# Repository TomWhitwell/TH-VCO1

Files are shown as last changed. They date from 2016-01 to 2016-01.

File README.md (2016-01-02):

# TH-VCO1

This is a Eurorack Layout for the [Thomas Henry VCO 1](http://www.birthofasynth.com/Thomas_Henry/Pages/VCO-1.html) Oscillator. 

**NB: All rights to this design rest with Thomas Henry. I do not claim or grant any copyright or license to this design. I am not selling any boards. I have not been able to contact Thomas, and will take this page down if he asks me to.** 

I made very minor changes from Thomas' original to make it work on 12v - detailed here: https://muffwiggler.com/forum/viewtopic.php?t=49671

This layout is for a modern LM13700 OTA replacing the old 3080, with a That 340 chip providing the matched transistor pairs. The only other non-standard components are a [2K 3300ppm Tempco](https://www.thonk.co.uk/shop/tempco-resistor-anakeohm-1-3300ppm-x3/) as R2, and a Polystyrene 1nf cap as C3.  

It all works very well, fantastic FM, nice looking and sounding sines. I was able to trim it to 4-5 octaves before getting bored. I haven't used multi-turn trimmers, so it might be harder to trim more accurately. On my second build I haven't trimmed anything, and it works beautifully for my needs. 

Quick demo here: https://www.instagram.com/p/_etQT6DmdM/

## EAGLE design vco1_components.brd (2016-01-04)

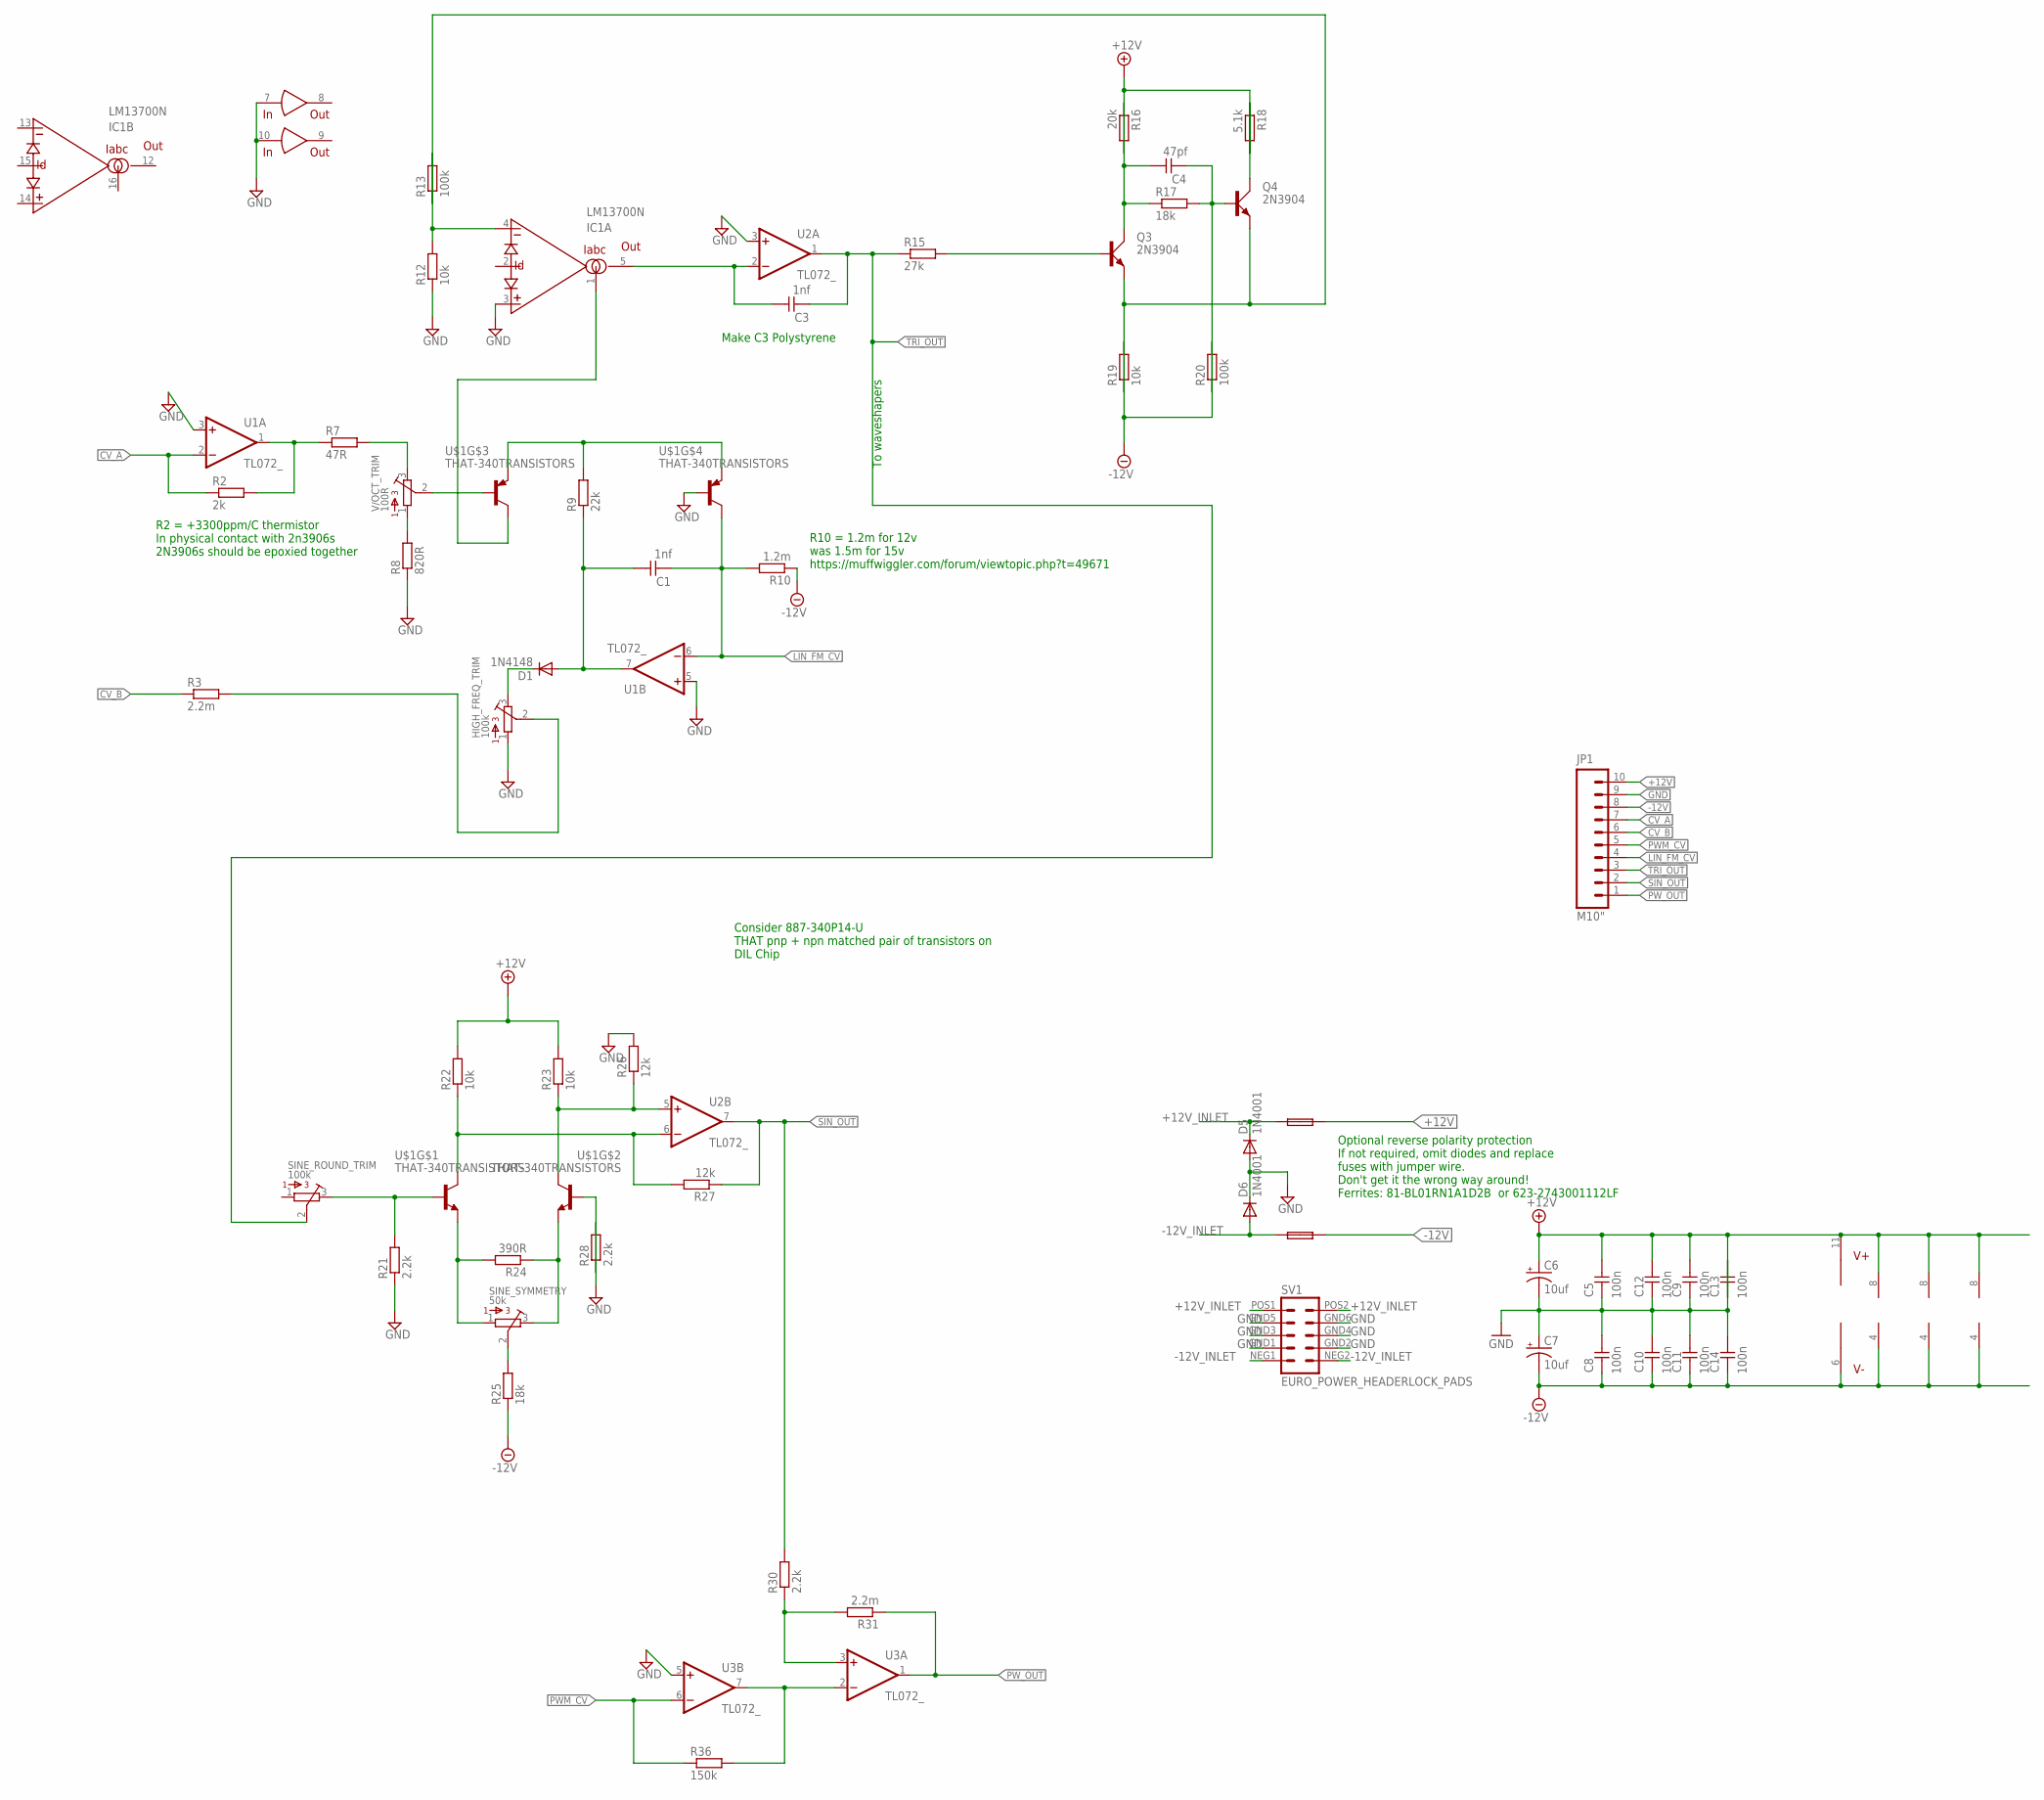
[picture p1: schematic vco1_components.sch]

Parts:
C1, C3: 1nf; C050-024X044
C4: 47pf; C050-024X044
C5, C8, C9, C10, C11, C12, C13, C14: 100n; C050-024X044
C6, C7: 10uf; CPOL-RADIAL-10UF-25V
D1: 1N4148; DO35-7
D5, D6: 1N4001; DO41-10
F1, F2: FUSE; C050H075X075
HIGH_FREQ_TRIM: 100k; BOURNS_3362P_TRIMMER
IC1: LM13700N; DIL16
JP1: M10"; 1X10
Q3, Q4: 2N3904; TO92D
R2: 2k; 7MM_RESISTOR
R3, R31: 2.2m; 7MM_RESISTOR
R7: 47R; 7MM_RESISTOR
R8: 820R; 7MM_RESISTOR
R9: 22k; 7MM_RESISTOR
R10: 1.2m; 7MM_RESISTOR
R12, R19, R22, R23: 10k; 7MM_RESISTOR
R13, R20: 100k; 7MM_RESISTOR
R15: 27k; 7MM_RESISTOR
R16: 20k; 7MM_RESISTOR
R17, R25: 18k; 7MM_RESISTOR
R18: 5.1k; 7MM_RESISTOR
R21, R28, R30: 2.2k; 7MM_RESISTOR
R24: 390R; 7MM_RESISTOR
R26, R27: 12k; 7MM_RESISTOR
R36: 150k; 7MM_RESISTOR
SINE_ROUND_TRIM: 100k; BOURNS_3362P_TRIMMER
SINE_SYMMETRY: 50k; BOURNS_3362P_TRIMMER
SV1: EURO_POWER_HEADERLOCK_PADS; EURO_PWR_HEADER_LOCK
U1, U2, U3: TL072_; DIL08
U$1: THAT-340TRANSISTORS; THAT340
V/OCT_TRIM: 100R; BOURNS_3362P_TRIMMER

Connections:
+12V: C5.1, C6.1 (+), C9.1, C12.1, C13.2, F1.2, IC1.11 (V+), JP1.10, R16.2, R18.2, R22.2, R23.2, U1.8 (V+), U2.8 (V+), U3.8 (V+)
+12V_INLET: D5.C, F1.1, SV1.POS1 (10), SV1.POS2 (9)
-12V: C7.2 (-), C8.2, C10.2, C11.2, C14.2, F2.2, IC1.6 (V-), JP1.8, R10.1, R19.2, R20.2, R25.1, U1.4 (V-), U2.4 (V-), U3.4 (V-)
-12V_INLET: D6.A, F2.1, SV1.NEG1 (2), SV1.NEG2 (1)
CV_A: JP1.7, R2.1, U1.2 (-IN)
CV_B: JP1.6, R3.1
GND: C5.2, C6.2 (-), C7.1 (+), C8.1, C9.2, C10.1, C11.1, C12.2, C13.1, C14.1, D5.A, D6.C, HIGH_FREQ_TRIM.1, IC1.3 (+IN), IC1.7 (IN), IC1.10 (IN), JP1.9, R8.1, R12.1, R21.1, R26.2, R28.2, SV1.GND1 (4), SV1.GND2 (3), SV1.GND3 (6), SV1.GND4 (5), SV1.GND5 (8), SV1.GND6 (7), U1.3 (+IN), U1.5 (+IN), U2.3 (+IN), U3.5 (+IN), U$1.9 (B)
LIN_FM_CV: C1.2, JP1.4, R10.2, U1.6 (-IN), U$1.8 (C)
unnamed: R2.2, R7.1, U1.1 (OUT)
unnamed: R7.2, V/OCT_TRIM.3
unnamed: R8.2, V/OCT_TRIM.1
unnamed: U$1.6 (B), V/OCT_TRIM.2
unnamed: R9.2, U$1.5 (E), U$1.10 (E)
unnamed: IC1.1 (IABC), U$1.7 (C)
unnamed: C1.1, D1.A, R9.1, U1.7 (OUT)
unnamed: D1.C, HIGH_FREQ_TRIM.3
unnamed: HIGH_FREQ_TRIM.2, R3.2
unnamed: IC1.4 (-IN), R12.2, R13.2
unnamed: C3.1, IC1.5 (OUT), U2.2 (-IN)
unnamed: Q3.B, R15.2
unnamed: C4.1, Q3.C, R16.1, R17.1
unnamed: R21.2, SINE_ROUND_TRIM.3, U$1.2 (B)
unnamed: C4.2, Q4.B, R17.2, R20.1
unnamed: Q4.C, R18.1
unnamed: R25.2, SINE_SYMMETRY.2
unnamed: Q3.E, Q4.E, R13.1, R19.1
unnamed: R22.1, R27.2, U2.6 (-IN), U$1.1 (C)
unnamed: R23.1, R26.1, U2.5 (+IN), U$1.14 (C)
unnamed: R24.2, SINE_SYMMETRY.1, U$1.3 (E)
unnamed: R24.1, SINE_SYMMETRY.3, U$1.12 (E)
unnamed: R28.1, U$1.13 (B)
unnamed: R30.1, R31.2, U3.3 (+IN)
unnamed: R36.2, U3.2 (-IN), U3.7 (OUT)
PWM_CV: JP1.5, R36.1, U3.6 (-IN)
PW_OUT: JP1.1, R31.1, U3.1 (OUT)
SIN_OUT: JP1.2, R27.1, R30.2, U2.7 (OUT)
TRI_OUT: C3.2, JP1.3, R15.1, SINE_ROUND_TRIM.2, U2.1 (OUT)

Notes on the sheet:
To waveshapers
R2 = +3300ppm/C thermistor In physical contact with 2n3906s 2N3906s should be epoxied together
Make C3 Polystyrene
R10 = 1.2m for 12v was 1.5m for 15v https://muffwiggler.com/forum/viewtopic.php?t=49671
Consider 887-340P14-U THAT pnp + npn matched pair of transistors on DIL Chip
Optional reverse polarity protection If not required, omit diodes and replace fuses with jumper wire. Don't get it the wrong way around! Ferrites: 81-BL01RN1A1D2B or 623-2743001112LF

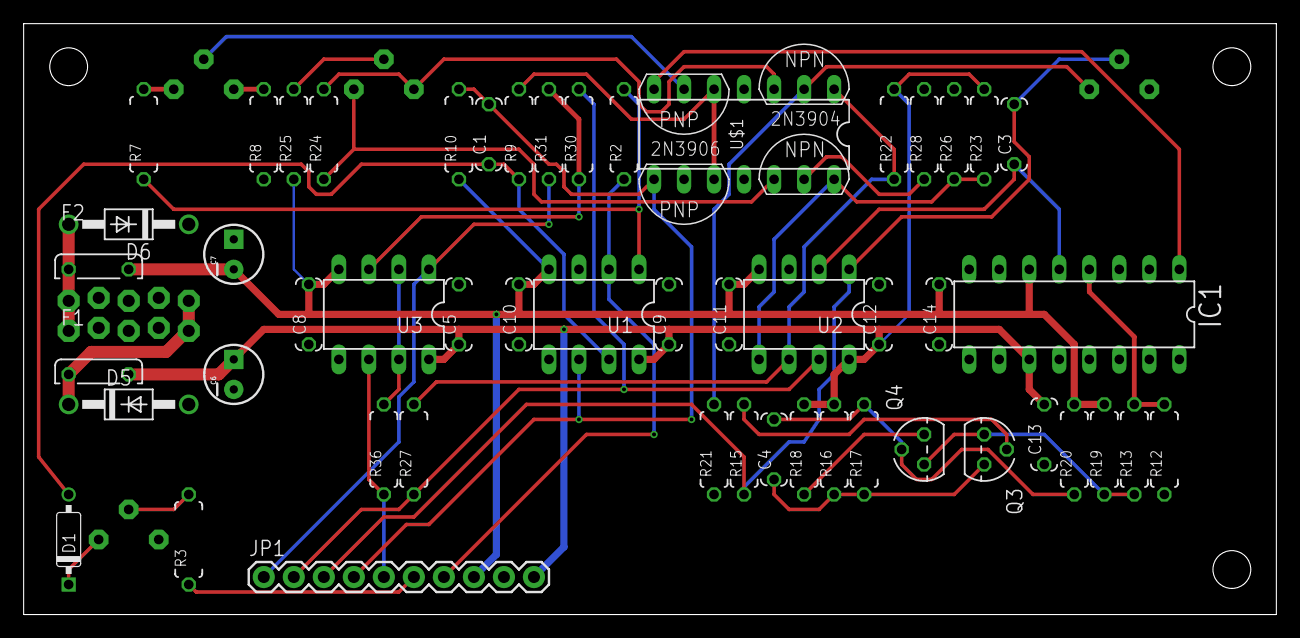
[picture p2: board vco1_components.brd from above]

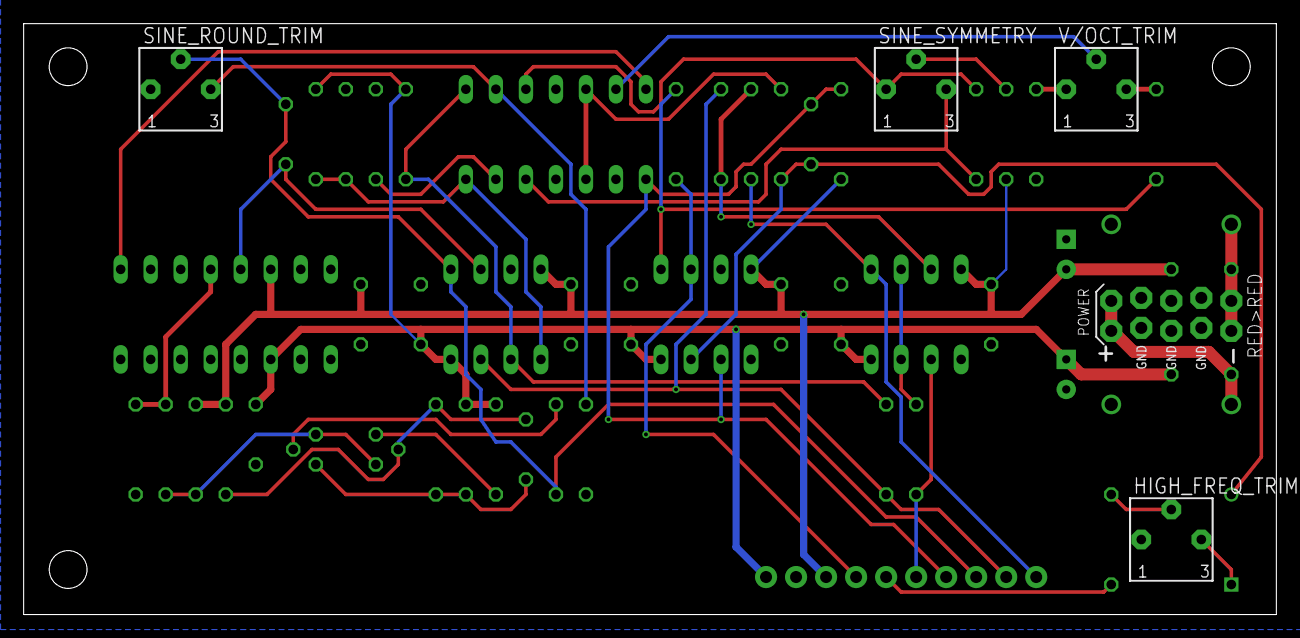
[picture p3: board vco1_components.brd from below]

Board: 4 copper layers, 106.0 x 50.0 mm, 59 parts (5 on the bottom side), 37 nets.

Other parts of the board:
U$2, U$3, U$4: MOUNTING_HOLE

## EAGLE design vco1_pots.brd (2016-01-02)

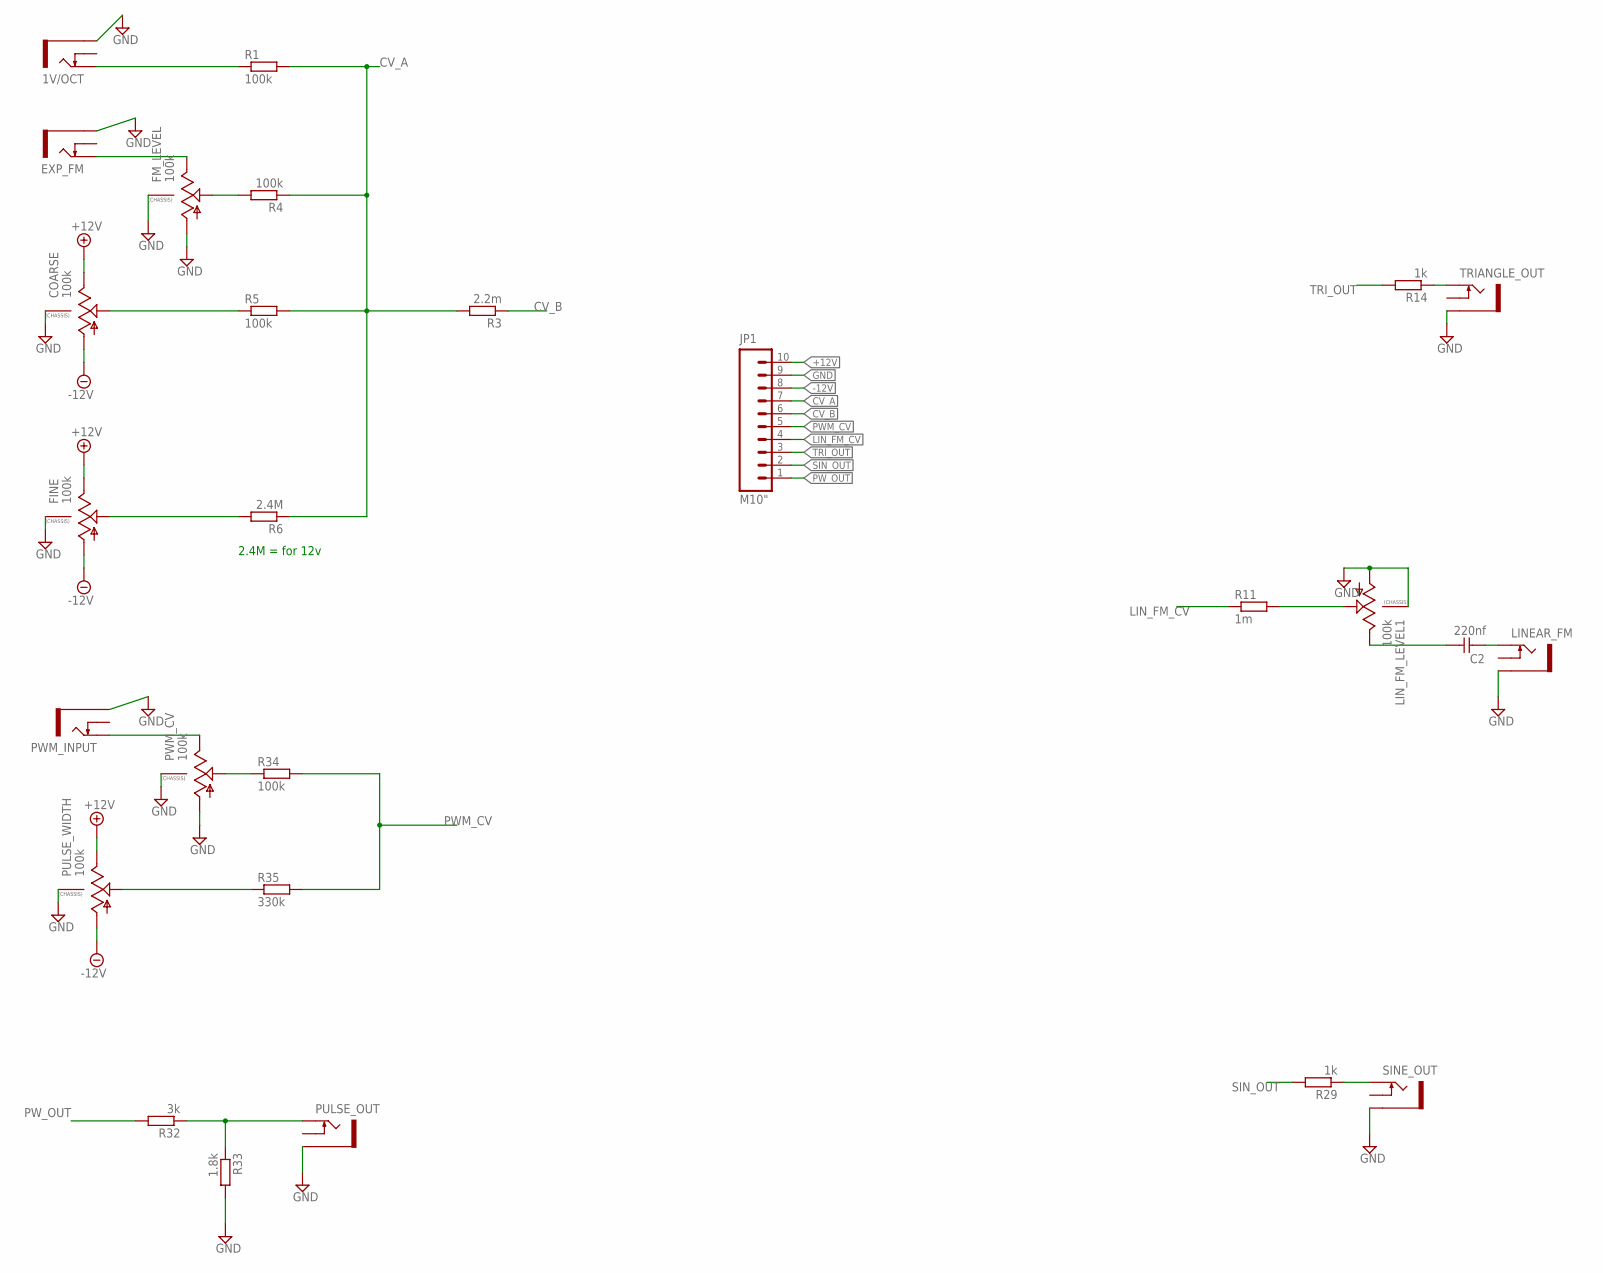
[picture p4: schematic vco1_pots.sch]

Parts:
1V/OCT: THONKICONNNEW; WQP-PJ301M-12_JACK
C2: 220nf; C050-024X044
COARSE: 100k; 9MM_SNAP-IN_POT
EXP_FM: THONKICONNNEW; WQP-PJ301M-12_JACK
FINE: 100k; 9MM_SNAP-IN_POT
FM_LEVEL: 100k; 9MM_SNAP-IN_POT
JP1: M10"; 1X10
LINEAR_FM: THONKICONNNEW; WQP-PJ301M-12_JACK
LIN_FM_LEVEL1: 100k; 9MM_SNAP-IN_POT
PULSE_OUT: THONKICONNNEW; WQP-PJ301M-12_JACK
PULSE_WIDTH: 100k; 9MM_SNAP-IN_POT
PWM_CV: 100k; 9MM_SNAP-IN_POT
PWM_INPUT: THONKICONNNEW; WQP-PJ301M-12_JACK
R1, R4, R5, R34: 100k; 7MM_RESISTOR
R3: 2.2m; 7MM_RESISTOR
R6: 2.4M; 7MM_RESISTOR
R11: 1m; 7MM_RESISTOR
R14, R29: 1k; 7MM_RESISTOR
R32: 3k; 7MM_RESISTOR
R33: 1.8k; 7MM_RESISTOR
R35: 330k; 7MM_RESISTOR
SINE_OUT: THONKICONNNEW; WQP-PJ301M-12_JACK
TRIANGLE_OUT: THONKICONNNEW; WQP-PJ301M-12_JACK

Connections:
+12V: COARSE.3 (E), FINE.3 (E), JP1.10, PULSE_WIDTH.3 (E)
-12V: COARSE.1 (A), FINE.1 (A), JP1.8, PULSE_WIDTH.1 (A)
CV_A: JP1.7, R1.2, R3.2, R4.1, R5.2, R6.1
CV_B: JP1.6, R3.1
GND: 1V/OCT.P$3_SLEEVE (SLEEVE), COARSE.CHASSIS2, EXP_FM.P$3_SLEEVE (SLEEVE), FINE.CHASSIS2, FM_LEVEL.1 (A), FM_LEVEL.CHASSIS2, JP1.9, LINEAR_FM.P$3_SLEEVE (SLEEVE), LIN_FM_LEVEL1.1 (A), LIN_FM_LEVEL1.CHASSIS2, PULSE_OUT.P$3_SLEEVE (SLEEVE), PULSE_WIDTH.CHASSIS2, PWM_CV.1 (A), PWM_CV.CHASSIS2, PWM_INPUT.P$3_SLEEVE (SLEEVE), R33.2, SINE_OUT.P$3_SLEEVE (SLEEVE), TRIANGLE_OUT.P$3_SLEEVE (SLEEVE)
LIN_FM_CV: JP1.4, R11.1
unnamed: 1V/OCT.P$1_TIP (TIP), R1.1
unnamed: EXP_FM.P$1_TIP (TIP), FM_LEVEL.3 (E)
unnamed: FM_LEVEL.2 (S), R4.2
unnamed: COARSE.2 (S), R5.1
unnamed: FINE.2 (S), R6.2
unnamed: LIN_FM_LEVEL1.2 (S), R11.2
unnamed: R14.1, TRIANGLE_OUT.P$1_TIP (TIP)
unnamed: C2.1, LIN_FM_LEVEL1.3 (E)
unnamed: C2.2, LINEAR_FM.P$1_TIP (TIP)
unnamed: R29.1, SINE_OUT.P$1_TIP (TIP)
unnamed: PULSE_OUT.P$1_TIP (TIP), R32.1, R33.1
unnamed: PWM_CV.3 (E), PWM_INPUT.P$1_TIP (TIP)
unnamed: PWM_CV.2 (S), R34.1
unnamed: PULSE_WIDTH.2 (S), R35.1
PWM_CV: JP1.5, R34.2, R35.2
PW_OUT: JP1.1, R32.2
SIN_OUT: JP1.2, R29.2
TRI_OUT: JP1.3, R14.2

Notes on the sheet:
2.4M = for 12v

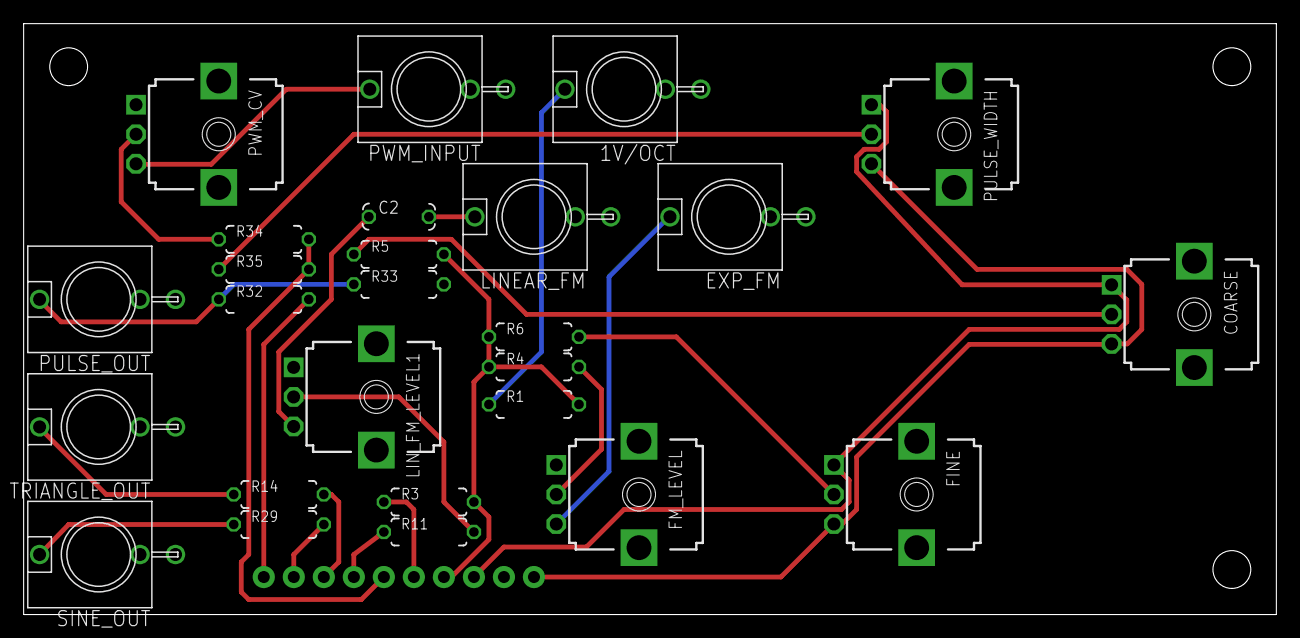
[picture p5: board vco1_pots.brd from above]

Board: 4 copper layers, 106.0 x 50.0 mm, 30 parts (1 on the bottom side), 24 nets.

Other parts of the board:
U$1, U$2, U$3: MOUNTING_HOLE

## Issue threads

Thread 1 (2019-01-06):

Reverse polarity protection / ferrite beads?

tsujigiri, 2019-01-06:
Hi,
please excuse my noob question, but I'm having a bit of trouble interpreting the schematic. I get the idea behind the combination of a diode and a fuse as a protection against reverse polarity. I'm a bit thrown off by the "Ferrites: XXX or XXX" part, though. This isn't part of the reverse polarity protection but protection against HF noise, right? Is this meant to be an either/or type of situation?

Cheers!

TomWhitwell, 2019-01-06:
That's the idea - the ferrites are for noise.

I think there's an element of Cargo Cult design to some of this stuff...

Closed 2019-01-06.

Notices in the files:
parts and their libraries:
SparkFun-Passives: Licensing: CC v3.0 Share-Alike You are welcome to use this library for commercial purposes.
